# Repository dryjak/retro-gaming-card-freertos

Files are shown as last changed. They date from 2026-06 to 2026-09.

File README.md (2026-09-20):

# 🎮 Interactive PCB Business Card & Pocket Console

## 📖 Overview
This project is a fully functional, credit-card-sized (53x85 mm) interactive business card that doubles as a minimalist handheld game console. Powered by an STM32 (prototype STM32F411RE, final version STM32C562KET) microcontroller and a LiPo battery, it was designed from scratch in KiCad to showcase complete hardware-software co-design. 

retroGameCard_Front

The goal of this project was to merge aesthetics with robust embedded engineering, tackling challenges such as mechanical constraints, power path optimization, and bare-metal/RTOS firmware development.

## ⚙️ Hardware Architecture
The board is designed with a focus on stability and signal integrity, featuring a sleek matte black soldermask and hidden testing interfaces.

* **Microcontroller:** STM32 series (prototype STM32F411RE, final version STM32C562KET), managing game logic and peripheral communication.
* **Display:** I2C OLED screen for high-contrast, low-power graphics.
* **Power Management:** Custom power path featuring a LiPo charging IC and a Low-Dropout Regulator (LDO) optimized for maximum battery life (minimizing voltage dropout).
* **PCB Layout Highlights:**
  * Mechanical collision avoidance (precise component placement avoiding mounting holes).
  * Concealed bottom-layer SWD Test Points (SWDIO, SWCLK, GND, 3.3V) to maintain a clean aesthetic on the front panel.

## 💻 Firmware & Software
The firmware is written in **C**, focusing on hardware abstraction and efficient resource management.
* Custom made liblaries for menu and games.
* (Optional for future) Power-saving modes to prevent LiPo over-discharge.
* (Optional for future) RTOS implementation for task scheduling (e.g., separating rendering tasks from button input polling).

The view of the PCB

retroGameCard_Front

retroGameCard_Back

Schematic
[Schematic.pdf](https://github.com/user-attachments/files/29943936/Schematic.pdf)

Layout
[Layout front.pdf](https://github.com/user-attachments/files/29943942/Layout.front.pdf)
[Lauout back.pdf](https://github.com/user-attachments/files/29943943/Lauout.back.pdf)

Basic schematic of STM32C562KET6

obraz

## 🗺️ System Block Diagram
```text
[ LiPo Battery ] --> [ Charger IC ] --> [ Low-Dropout (LDO) 3.3V ] 
                                                 |
                                                 v
[ User Buttons ] ------------------------> [ STM32 MCU ]
                                                 |
[ SWD Test Points ] <--------------------/       v
                                           [ OLED Display ]

```
Things to change:
1) Footprint 0.96 inch display - I used different pcb size - mistake
2) Add Rx and Tx pins for debugging
3) Change voltage devider placement, connection - connect it after on/off switch
4) Change footprint for battery connection

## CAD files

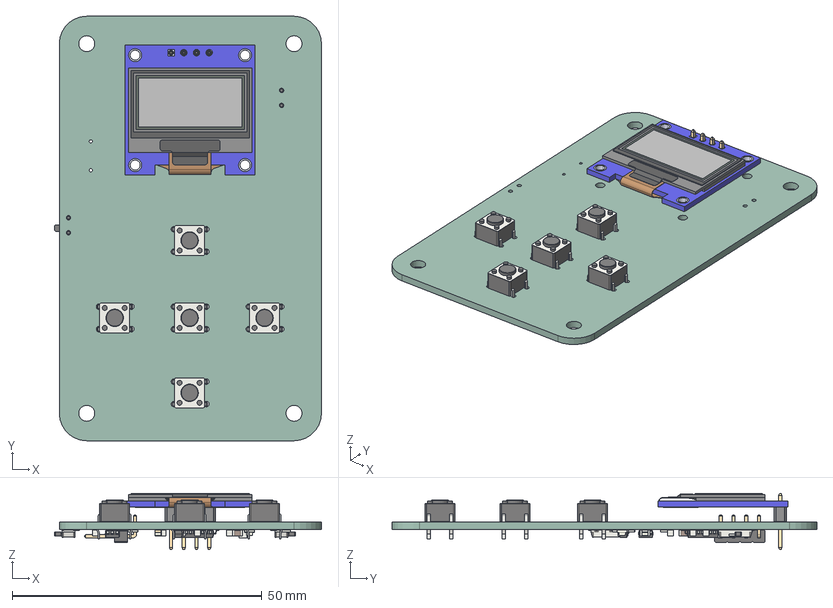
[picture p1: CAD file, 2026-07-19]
3D models/PCB_3D.step
53.5 x 85.0 x 11.3 mm
SW_PUSH_6mm x 5
DM-OLED096-636_Module
DM-OLED096-636_Panel
R_0805_2012Metric x 8
LQFP-32_7x7mm_P0.8mm
SOT-23-5 x 2
C_0805_2012Metric x 9
C_1206_3216Metric
LED_0805_2012Metric x 2
PinHeader_1x04_P254mm_Horizontal
Fusion_sp x 2
retroGameCard_PCB

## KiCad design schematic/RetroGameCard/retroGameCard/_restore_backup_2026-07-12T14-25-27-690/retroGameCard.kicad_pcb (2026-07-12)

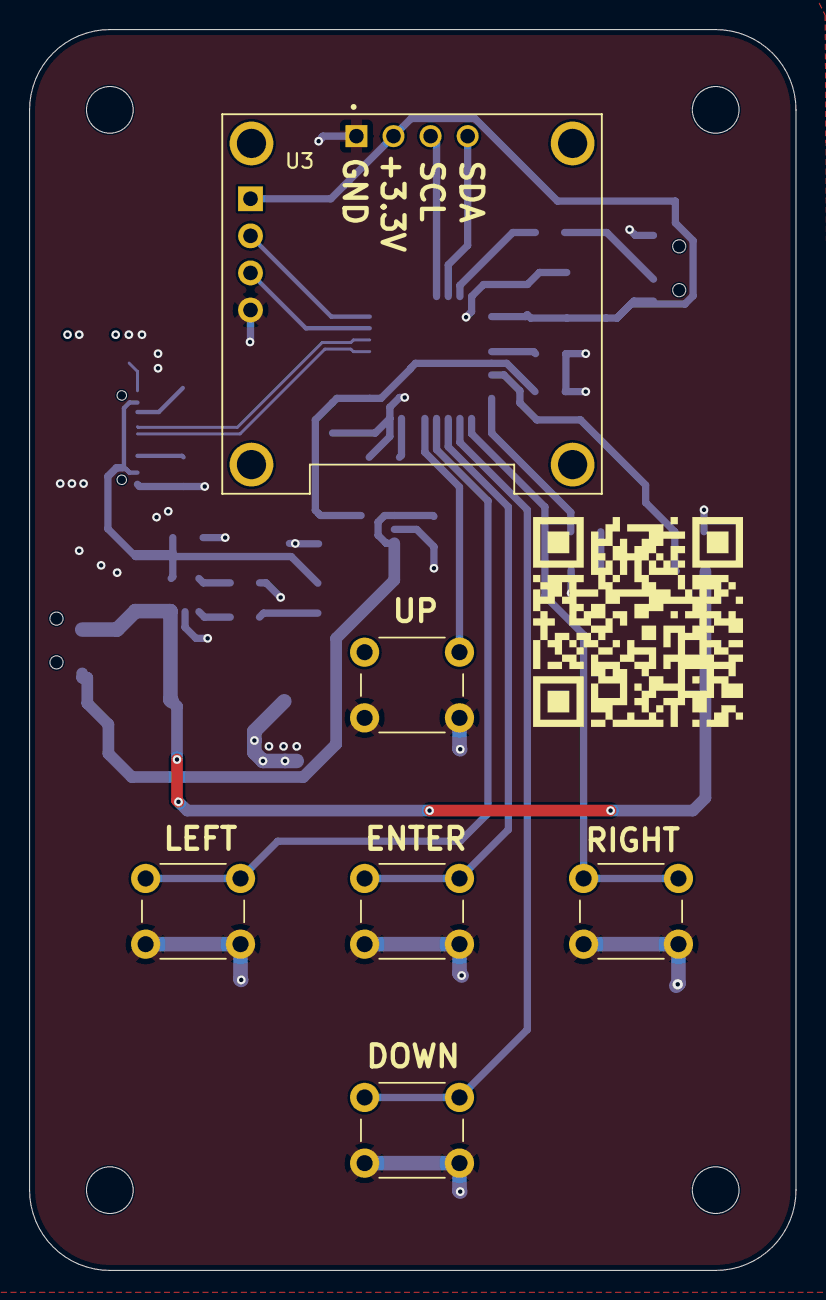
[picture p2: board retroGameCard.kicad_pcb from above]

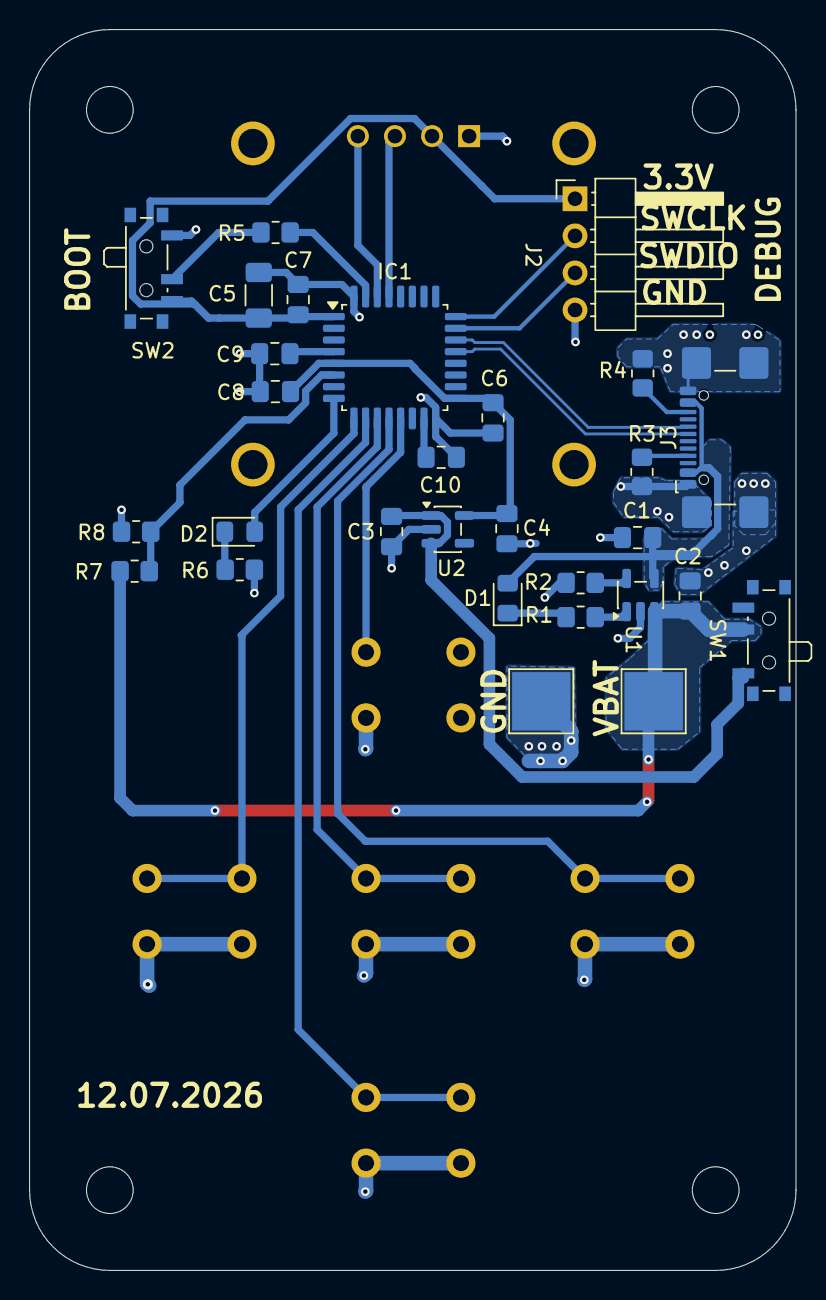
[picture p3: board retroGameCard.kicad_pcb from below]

Board: 2 copper layers, 52.5 x 85.0 mm, 38 parts (28 on the bottom side), 28 nets.

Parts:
C1, C2, C3, C4, C10: 4.7u; C_0805_2012Metric_Pad1.18x1.45mm_HandSolder
C5: 10u; C_1206_3216Metric_Pad1.33x1.80mm_HandSolder
C6, C7, C8, C9: 100n; C_0805_2012Metric_Pad1.18x1.45mm_HandSolder
C11: 1s lipo battery; Bez_nazwy_1
D1, D2: RED; LED_0805_2012Metric_Pad1.15x1.40mm_HandSolder
H1, H2, H3, H4: MountingHole; MountingHole_3.2mm_M3
IC1: STM32C562KET6; LQFP-32_7x7mm_P0.8mm
J2: Conn_01x04_Pin; PinHeader_1x04_P2.54mm_Horizontal
J3: USB_C_Receptacle_USB2.0_16P; USB_C_Receptacle_GCT_USB4110
R1: 470; R_0805_2012Metric_Pad1.20x1.40mm_HandSolder
R2, R6: 2k; R_0805_2012Metric_Pad1.20x1.40mm_HandSolder
R3, R4: 5.1k; R_0805_2012Metric_Pad1.20x1.40mm_HandSolder
R5: 10k; R_0805_2012Metric_Pad1.20x1.40mm_HandSolder
R7, R8: 100k; R_0805_2012Metric_Pad1.20x1.40mm_HandSolder
SW1: SW_Slide_DPDT; SW_SPDT_PCM12
SW2: SW_SPDT; SW_SPDT_PCM12
SW3, SW4, SW5, SW6, SW7: SW_Push; SW_PUSH_6mm
U1: MCP73831-2-OT; SOT-23-5
U2: AP2112K-3.3; SOT-23-5
U3: DM-OLED096-636; MODULE_DM-OLED096-636

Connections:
+3.3V: C4.1, C5.1, C6.1, C7.1, C8.1, IC1.1 (VDD_1), IC1.5 (VREF+), IC1.17 (VDD_2), J2.1, SW2.3 (C), U2.5 (VOUT), U3.2 (VCC_IN)
/ADC_VBATT: IC1.6 (PA0), R7.1, R8.2
/BOOT0: IC1.31 (PB8-BOOT0), R5.2
/DOWN: IC1.10 (PA4), SW4.1
/ENTER: IC1.11 (PA5), SW5.1
/LED: D2.2 (A), IC1.8 (PA2)
/LEFT: IC1.12 (PA6), SW3.1
/NRST: C9.1, IC1.4 (NRST)
/OLED_I2C_SCL: IC1.29 (PB6), U3.3 (SCL)
/OLED_I2C_SDA: IC1.30 (PB7), U3.4 (SDA)
/RIGHT: IC1.9 (PA3), SW7.1
/SWCLK: IC1.24 (PA14), J2.2
/SWDIO: IC1.23 (PA13), J2.3
/SW_BOOT: R5.1, SW2.2 (B)
/UP: IC1.13 (PA7), SW6.1
/USB_D+: IC1.22 (PA12), J3.A6 (D+), J3.B6 (D+)
/USB_D-: IC1.21 (PA11), J3.A7 (D-), J3.B7 (D-)
/Vbat: C2.1, C11.1, R7.2, SW1.2 (B), U1.3 (V_{BAT})
GND: C1.2, C2.2, C3.2, C4.2, C5.2, C6.2, C7.2, C8.2, C9.2, C10.2, C11.2, IC1.16 (VSS_1), IC1.32 (VSS_2), J2.4, J3.A1 (GND), J3.A12 (GND), J3.B1 (GND), J3.B12 (GND), J3.S1 (SHIELD), R2.1, R3.2, R4.1, R6.1, R8.1, SW2.1 (A), SW3.2, SW4.2, SW5.2, SW6.2, SW7.2, U1.2 (V_{SS}), U2.2 (GND), U3.1 (GND)
unnamed: D1.1 (K), R1.2
unnamed: D2.1 (K), R6.2
unnamed: C10.1, IC1.15 (VCAP)
unnamed: J3.A5 (CC1), R3.1
unnamed: J3.B5 (CC2), R4.2
unnamed: R2.2, U1.5 (PROG)
unnamed: R1.1, U1.1 (STAT)
unnamed: C3.1, SW1.1 (A), U2.1 (VIN), U2.3 (EN)
VBUS: C1.1, D1.2 (A), J3.A4 (VBUS), J3.A9 (VBUS), J3.B4 (VBUS), J3.B9 (VBUS), U1.4 (V_{DD})

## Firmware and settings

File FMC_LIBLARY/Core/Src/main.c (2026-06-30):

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
/* Includes ------------------------------------------------------------------*/
#include "main.h"
#include "dma.h"
#include "i2c.h"
#include "usart.h"
#include "gpio.h"

/* USER CODE BEGIN Includes */
#include "SSD1306_OLED.h"
#include "GFX_BW.h"
#include "Button.h"
#include "GameConsoleMenu.h"
#include "fonts/fonts.h"
#include "GameSnake.h"
#include "FlappyBird.h"
/* USER CODE END Includes */


/* USER CODE BEGIN PV */
SSD1306_t OLED;

//Buttons
Button_t Enter, Up, Down, Left, Right;
uint8_t ButtonPressedFlag;

//Game console FSM
GameConsole_t Console;

/* USER CODE END PV */

void SystemClock_Config(void);
static void MX_NVIC_Init(void);
/* USER CODE BEGIN PFP */
void Snake_Confirm(void);
void Action_PlaySnake(void);

void Action_PlayFlappy(void);

void TurnLedOff(void);
void TurnLedOn(void);
void ToggleLed(void);

//Wrapper
void Action_MenuUp(void);
void Action_MenuDown(void);
void Action_MenuEnter(void);
void Action_MenuLeft(void);
void Action_MenuRight(void);




/* USER CODE END PFP */

/**
  * @brief  The application entry point.
  * @retval int
  */
int main(void)
{

  /* MCU Configuration--------------------------------------------------------*/

  /* Reset of all peripherals, Initializes the Flash interface and the Systick. */
  HAL_Init();

  /* Configure the system clock */
  SystemClock_Config();

  /* Initialize all configured peripherals */
  MX_GPIO_Init();
  MX_DMA_Init();
  MX_USART2_UART_Init();
  MX_I2C1_Init();

  /* Initialize interrupts */
  MX_NVIC_Init();
  /* USER CODE BEGIN 2 */
  SSD1306_Init(&OLED, 0x3C, &hi2c1);
  HAL_Delay(50);
  GFX_SetFont(font_8x5);
  SSD1306_Clear(BLACK);
  GFX_DrawString(10, 4, "RETRO GAME CONSOLE", WHITE, BLACK);
  GFX_DrawLine(0, 14, 127, 14, WHITE);

  GFX_DrawRectangle(44, 29, 30, 30, WHITE);
  GFX_DrawRectangle(54, 19, 30, 30, WHITE);

  GFX_DrawLine(44, 29, 54, 19, WHITE);
  GFX_DrawLine(73, 29, 83, 19, WHITE);
  GFX_DrawLine(44, 58, 54, 48, WHITE);
  GFX_DrawLine(73, 58, 83, 48, WHITE);

  GFX_DrawFillRectangle(56, 31, 6, 6, WHITE);
  SSD1306_Display(&OLED);
  HAL_Delay(4000);

  //Game console FSM initialization
  Console_Init(&Console);
//  Console_Draw(&Console, &OLED);

  //Initialize Buttons
  ButtonInit(&Up, ButtonUp_GPIO_Port, ButtonUp_Pin, 30, 500, 200);
  ButtonRegisterPressCallback(&Up, Action_MenuUp);
  ButtonRegisterLongPressCallback(&Up, TurnLedOff);
  ButtonRegisterRepeatCallback(&Up, ToggleLed);
  ButtonRegisterGoToIdleCallback(&Up, TurnLedOff);

  ButtonInit(&Enter, ButtonEnter_GPIO_Port, ButtonEnter_Pin, 30, 500, 200);
  ButtonRegisterPressCallback(&Enter, Action_MenuEnter);
  ButtonRegisterLongPressCallback(&Enter, TurnLedOff);
  ButtonRegisterRepeatCallback(&Enter, ToggleLed);
  ButtonRegisterGoToIdleCallback(&Enter, TurnLedOff);

  ButtonInit(&Down, ButtonDown_GPIO_Port, ButtonDown_Pin, 30, 500, 200);
  ButtonRegisterPressCallback(&Down, Action_MenuDown);
  ButtonRegisterLongPressCallback(&Down, TurnLedOff);
  ButtonRegisterRepeatCallback(&Down, ToggleLed);
  ButtonRegisterGoToIdleCallback(&Down, TurnLedOff);

  ButtonInit(&Left, ButtonLeft_GPIO_Port, ButtonLeft_Pin, 30, 500, 200);
  ButtonRegisterPressCallback(&Left, Action_MenuLeft);
  ButtonRegisterLongPressCallback(&Left, TurnLedOff);
  ButtonRegisterRepeatCallback(&Left, ToggleLed);
  ButtonRegisterGoToIdleCallback(&Left, TurnLedOff);

  ButtonInit(&Right, ButtonRight_GPIO_Port, ButtonRight_Pin, 30, 500, 200);
  ButtonRegisterPressCallback(&Right, Action_MenuRight);
  ButtonRegisterLongPressCallback(&Right, TurnLedOff);
  ButtonRegisterRepeatCallback(&Right, ToggleLed);
  ButtonRegisterGoToIdleCallback(&Right, TurnLedOff);


//DONE TODO: Add variable that shows us current brightness and mode in settings section
//TODO: Add About section
//DONE TODO: Add function for left and right button
 //TODO: Add second game
 //TODO: do electronic schematic in kicad
 //TODO: how to save settingss changed by user?
  /* USER CODE END 2 */

  /* Infinite loop */
  /* USER CODE BEGIN WHILE */
  while (1)
  {

	ButtonTask(&Up);
	ButtonTask(&Down);
	ButtonTask(&Enter);
	ButtonTask(&Left);
	ButtonTask(&Right);

/*
	if(HAL_GPIO_ReadPin(ButtonEnter_GPIO_Port, ButtonEnter_Pin) == GPIO_PIN_RESET
		  || HAL_GPIO_ReadPin(ButtonUp_GPIO_Port, ButtonUp_Pin) == GPIO_PIN_RESET
		  || HAL_GPIO_ReadPin(ButtonDown_GPIO_Port, ButtonDown_Pin) == GPIO_PIN_RESET
		  || HAL_GPIO_ReadPin(ButtonLeft_GPIO_Port, ButtonLeft_Pin) == GPIO_PIN_RESET
		  || HAL_GPIO_ReadPin(ButtonRight_GPIO_Port, ButtonRight_Pin) == GPIO_PIN_RESET)
	{
	  HAL_GPIO_WritePin(LedRed_GPIO_Port, LedRed_Pin, GPIO_PIN_SET);
	}
	else
	{
	  HAL_GPIO_WritePin(LedRed_GPIO_Port, LedRed_Pin, GPIO_PIN_RESET);
	}
	*/

	if (Console.CurrentSystemState == STATE_GAME_SNAKE)
	{
		Snake_UpdateLogic();

		// Rysujemy TYLKO wtedy, gdy logika tego zażąda (ruch lub śmierć)
		if (Snake.NeedsRedraw == 1) {
			Snake_Draw(&OLED);
			Snake.NeedsRedraw = 0; // Opuszczamy flagę
		}
	}/*
	else if(Console.CurrentSystemState == STATE_GAME_FLAPPY)
	{
		Flappy_UpdateLogic();

		if (Flappy.NeedsRedraw == 1)
		{
			Flappy_Draw(&OLED);
			Flappy.NeedsRedraw = 0;
		}
	}*/
	else
	{
		Console_Draw(&Console, &OLED);
	}

	HAL_Delay(10);
    /* USER CODE END WHILE */

    /* USER CODE BEGIN 3 */
  }
  /* USER CODE END 3 */
}

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
/* USER CODE BEGIN 4 */
void Snake_Confirm(void) {
    if (Snake.IsDead == 1) {
        // Go back to menu
        Console.CurrentSystemState = STATE_GAMES_MENU;
        Console.MenuCursorIndex = 0;
        Console.NeedsRedraw = 1;
    }
}

//change state MENU / game
void Action_PlaySnake(void) {
    // 1. Zmiana stanu systemu na grę
    Console.CurrentSystemState = STATE_GAME_SNAKE;

    // 2. Inicjalizacja gry (wąż ustawia się na środku, SpeedMs domyślnie na 150)
    Snake_Init();

    // 3. NADPISANIE PRĘDKOŚCI NA PODSTAWIE MENU
    // Zmienna Console.Settings[1] przechowuje indeks trybu (0=EASY, 1=NORMAL, 2=HARD)
    switch (Console.Settings[1]) {
        case EASY:
            Snake.SpeedMs = 250;
            break;
        case NORMAL:
            Snake.SpeedMs = 150;
            break;
        case HARD:
            Snake.SpeedMs = 130;
            break;
        default:
            Snake.SpeedMs = 150; // Zabezpieczenie (wartość domyślna)
            break;
    }
}
/*
void Action_PlayFlappy(void) {
    // 1. Zmiana stanu całego urządzenia na grę Flappy Bird
    Console.CurrentSystemState = STATE_GAME_FLAPPY;

    // 2. Zresetowanie fizyki (ptak ląduje na środku, rury się ustawiają)
    Flappy_Init();

    // 3. Konfiguracja poziomu trudności na podstawie opcji w Settings
    // Console.Settings[1] to nasz tryb (0=EASY, 1=NORMAL, 2=HARD)
    switch (Console.Settings[1]) {
        case EASY:
            Flappy.FrameRateMs = 40; // Wolniejsza fizyka - łatwiej reagować
            break;
        case NORMAL:
            Flappy.FrameRateMs = 30; // Standardowa prędkość
            break;
        case HARD:
            Flappy.FrameRateMs = 20; // Szybsza fizyka - mało czasu na reakcję!
            break;
        default:
            Flappy.FrameRateMs = 30;
            break;
    }
}
*/
//change display brightness
void Action_ChangeContrast()
{
	    uint32_t temp = Console.Settings[0] * 255;
	    uint8_t hardware_value = (uint8_t)(temp / 100);

	    // Używamy globalnej zmiennej OLED z main.c
	    SSD1306_Command(&OLED, SSD1306_SETCONTRAST);
	    SSD1306_Command(&OLED, hardware_value);
}


//wrapper
void Action_MenuUp(void) {
    if (Console.CurrentSystemState == STATE_GAME_SNAKE) {
        Snake_TurnUp();
    }/*
    else if (Console.CurrentSystemState == STATE_GAME_FLAPPY) {
        Flappy_Jump(); // Skok ptaka!
    }*/
    else {
        Console_MoveUp(&Console);
    }
    TurnLedOn();
}
void Action_MenuDown(void) {
    if (Console.CurrentSystemState == STATE_GAME_SNAKE) {
        Snake_TurnDown();
    }/*
    else if (Console.CurrentSystemState == STATE_GAME_FLAPPY) {
        // Puste! Ptak nie reaguje na strzałkę w dół.
    }*/
    else {
        Console_MoveDown(&Console);
    }
    TurnLedOn();
}

void Action_MenuEnter(void) {
    if (Console.CurrentSystemState == STATE_GAME_SNAKE) {
        Snake_Confirm();
    }/*
    else if (Console.CurrentSystemState == STATE_GAME_FLAPPY) {
		// Jeśli ptak zginął, Enter wraca do menu. Jeśli żyje, skacze!
		if (Flappy.IsDead) {
			Console.CurrentSystemState = STATE_GAMES_MENU;
			Console.MenuCursorIndex = 0;
			Console.NeedsRedraw = 1;
		} else {
			Flappy_Jump();
		}
	}*/
    else {
        Console_Enter(&Console);
    }
    TurnLedOn();
}

void Action_MenuLeft(void) {
    if (Console.CurrentSystemState == STATE_GAME_SNAKE) {
        Snake_TurnLeft();
    }/*
    else if (Console.CurrentSystemState == STATE_GAME_FLAPPY) {
        // Puste!
    }*/
    else {
        Console_MoveLeft(&Console);
    }
    TurnLedOn();
}
void Action_MenuRight(void) {
    if (Console.CurrentSystemState == STATE_GAME_SNAKE) {
        Snake_TurnRight();
    }/*
    else if (Console.CurrentSystemState == STATE_GAME_FLAPPY) {
        // Puste!
    }*/
    else {
        Console_MoveRight(&Console);
    }
    TurnLedOn();
}


//basic functions
void ToggleLed(void)
{
	HAL_GPIO_TogglePin(LedRed_GPIO_Port, LedRed_Pin);
}
void TurnLedOff(void)
{
	HAL_GPIO_WritePin(LedRed_GPIO_Port, LedRed_Pin, GPIO_PIN_RESET);
	ButtonPressedFlag = 0;
}
void TurnLedOn(void)
{
	HAL_GPIO_WritePin(LedRed_GPIO_Port, LedRed_Pin, GPIO_PIN_SET);
	ButtonPressedFlag = 1;
}
/* USER CODE END 4 */
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


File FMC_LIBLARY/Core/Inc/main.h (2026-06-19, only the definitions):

#define B1_Pin GPIO_PIN_13
#define B1_GPIO_Port GPIOC
#define USART_TX_Pin GPIO_PIN_2
#define USART_TX_GPIO_Port GPIOA
#define USART_RX_Pin GPIO_PIN_3
#define USART_RX_GPIO_Port GPIOA
#define LD2_Pin GPIO_PIN_5
#define LD2_GPIO_Port GPIOA
#define ButtonUp_Pin GPIO_PIN_6
#define ButtonUp_GPIO_Port GPIOA
#define ButtonRight_Pin GPIO_PIN_7
#define ButtonRight_GPIO_Port GPIOA
#define ButtonLeft_Pin GPIO_PIN_7
#define ButtonLeft_GPIO_Port GPIOC
#define ButtonEnter_Pin GPIO_PIN_9
#define ButtonEnter_GPIO_Port GPIOA
#define TMS_Pin GPIO_PIN_13
#define TMS_GPIO_Port GPIOA
#define TCK_Pin GPIO_PIN_14
#define TCK_GPIO_Port GPIOA
#define SWO_Pin GPIO_PIN_3
#define SWO_GPIO_Port GPIOB
#define LedRed_Pin GPIO_PIN_5
#define LedRed_GPIO_Port GPIOB
#define ButtonDown_Pin GPIO_PIN_6
#define ButtonDown_GPIO_Port GPIOB

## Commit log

2026-06-16 fixed bugs, initialization is working
    [main.c]
2026-06-19 added button liblary to the project
2026-06-19 test button
2026-06-20 test buttons
2026-06-23 added all buttons
2026-06-26 added left and right button
2026-06-26 buttons left and right are working
2026-06-30 update bug in flppy bird game
    [main.c]
2026-06-30 changed oled i2c to dma, changes functions in oled lib
2026-06-30 made symbol and footprint for STM32C562KET6
    [retroGameCard.kicad_pcb, retroGameCard.kicad_sch]
2026-06-30 added power rails
    [retroGameCard.kicad_sch]
2026-07-07 Add basic schematic for STM32C562KET6
2026-07-08 added schematic for USB, debug and oled
    [retroGameCard.kicad_sch]
2026-07-08 added usb circut, to do battery manegement
    [retroGameCard.kicad_sch]
2026-07-08 added charging 1s lipo
    [retroGameCard.kicad_sch]
2026-07-08 final schematic
    [retroGameCard.kicad_sch]
2026-07-08 added footprints to symbols
    [retroGameCard.kicad_sch]
2026-07-08 added footprints to symbols and changed ssd1306 footprint
    [retroGameCard.kicad_sch]
2026-07-09 changed footprints and added layout
    [retroGameCard.kicad_pcb]
2026-07-09 changed shemat footprints
    [retroGameCard.kicad_sch]
2026-07-10 changed footprints and oled
    [retroGameCard.kicad_sch]
2026-07-10 changed layout
    [retroGameCard.kicad_pcb]
2026-07-10 update schematic
    [retroGameCard.kicad_sch]
2026-07-10 update layout
    [retroGameCard.kicad_pcb]
2026-07-11 added mounting holes in schematic
    [retroGameCard.kicad_sch]
2026-07-11 added boundary of the pcb and holes for m3 screw
    [retroGameCard.kicad_pcb]
2026-07-11 added traces to PCB
    [retroGameCard.kicad_pcb]
2026-07-12 finished board - ready to be manufacture
    [retroGameCard.kicad_pcb, retroGameCard.kicad_sch]
2026-07-12 Update README with PCB images and schematic
    Added images and descriptions for PCB views and STM32C562KET6 schematic.
2026-07-12 Add schematic section to README
    Added schematic information and a link to the PDF.
2026-07-12 Add image to README for STM32C562KET6 schematic
2026-07-19 added 3d model of the pcb
    [PCB_3D.step]
2026-07-19 added 3d model of the case
2026-07-31 test code to check board
2026-08-03 added i2c connection
2026-08-03 tried to make i2c communication in hal 2
2026-08-05 update main - bug with buttons initialization
    [main.c]
2026-08-05 fixed some bugs, snake is working
    [Button.c, GameSnake.c, main.c]
2026-08-10 changed ioc file, added adc and timer
2026-08-11 added adc to read vbat
2026-08-18 added new ioc file to test adc
2026-08-18 program to test adc, something is not working - i guess it is hardware error
    [main.c, main.h]
2026-08-18 added dma to oled display
2026-08-18 added value of battery to display
2026-08-18 fixed some bugs in flappy bird liblary
    [GameFlappy.c]
2026-09-15 Document changes needed for PCB and display
    Added a section for changes needed in the README.
2026-09-20 added test file for adc measurement
2026-09-20 tried to make adc work
2026-09-21 Added calculating battery percentage
2026-09-21 added reaction to battery level
2026-09-22 test adc with timer that enables adc each 10s
2026-09-22 fixed bug with clocks
    [main.c]
2026-09-23 added adc measurements and changed to battery percentage
2026-09-23 fixed bug with battery level
2026-09-23 fixed bug with redrawing
    [main.c]
2026-09-26 added liblary that check battery voltage level
2026-10-09 generated ioc project to check vrefint adc measurements

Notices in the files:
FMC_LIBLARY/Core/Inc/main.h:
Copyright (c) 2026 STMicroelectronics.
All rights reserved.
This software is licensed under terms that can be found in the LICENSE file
